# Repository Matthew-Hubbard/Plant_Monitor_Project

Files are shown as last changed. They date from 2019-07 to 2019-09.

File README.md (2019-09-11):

<h1 align="center" font-weight="bold">Wireless Plant Monitoring</h1>

### About
**Goal:** To host a website that tracks plant data through wireless sensors.

I'm developing a system of Arduinos with sensors to monitor plants connected over RF to a master module. The master module has an ESP8266 WiFi chip that uploads data to a Django web server via HTTP POST request.

### [Click here to check out the website!](http://matthewhubbard.pythonanywhere.com "Plant Monitor Website")

Demo

<h2 align="center">System Diagram</h2>

<p align="center">
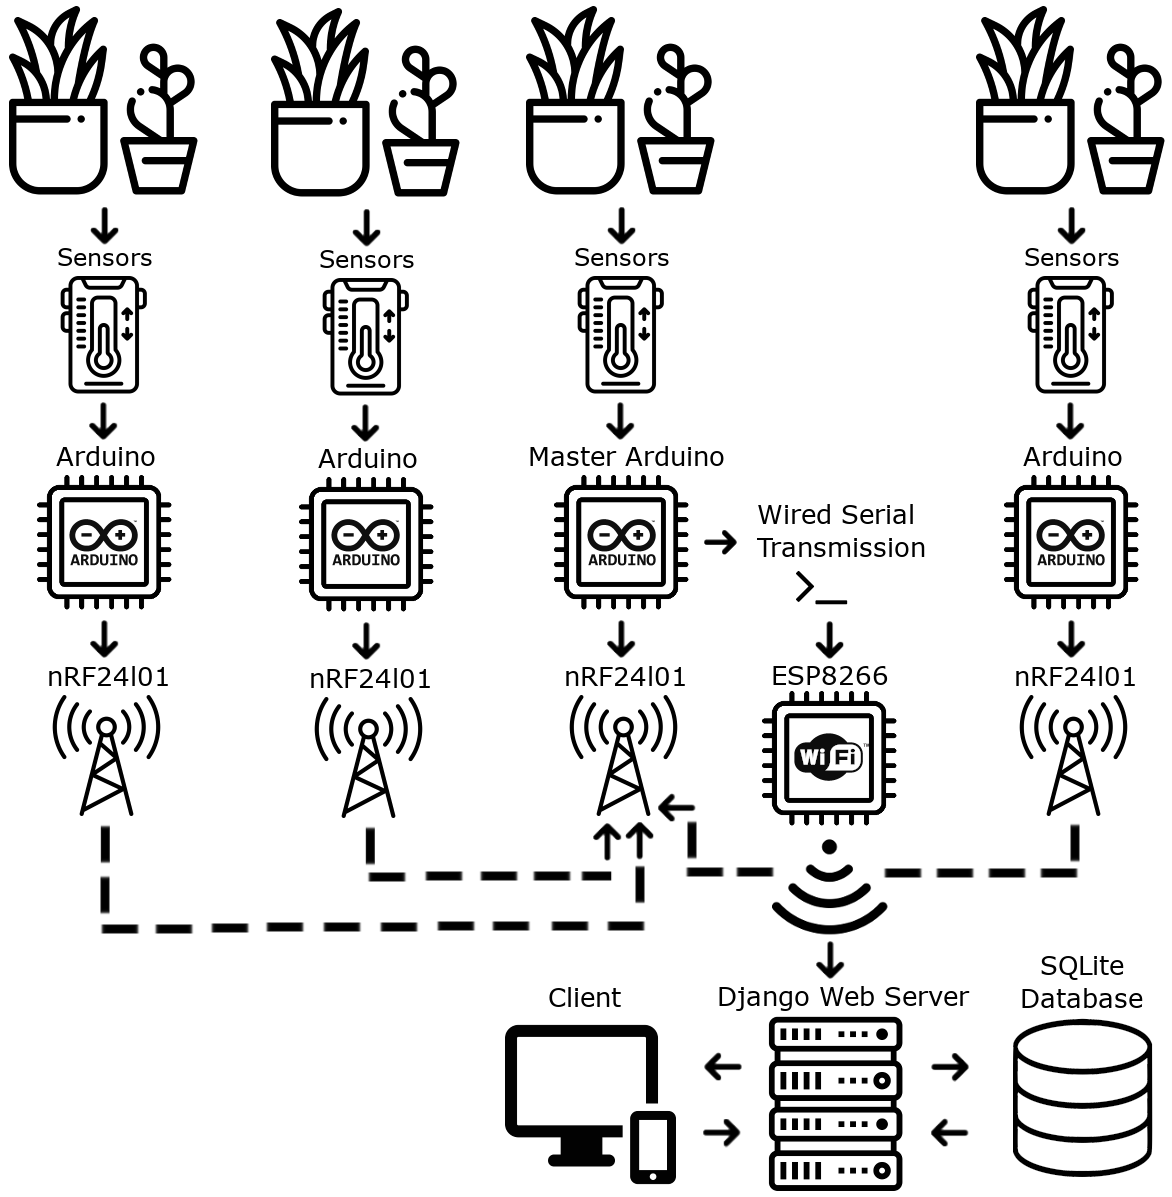
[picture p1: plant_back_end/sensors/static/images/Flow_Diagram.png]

</p>

<h2 align="center">Technology Stack</h2>
<hr>

<p align="center">

</p>

<p align="center">
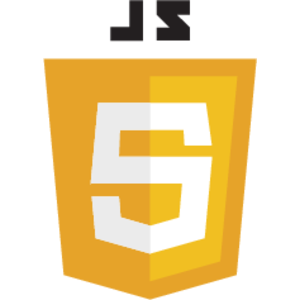
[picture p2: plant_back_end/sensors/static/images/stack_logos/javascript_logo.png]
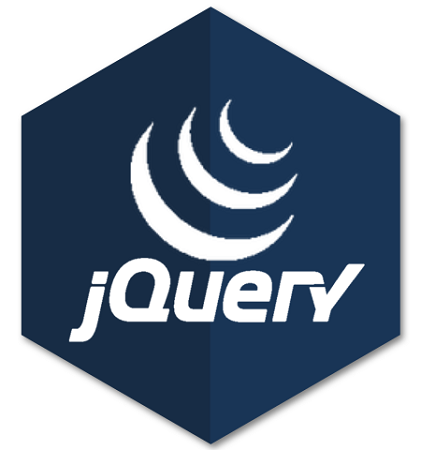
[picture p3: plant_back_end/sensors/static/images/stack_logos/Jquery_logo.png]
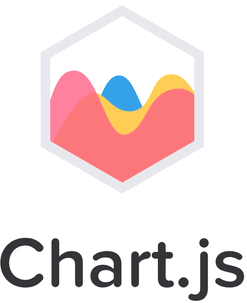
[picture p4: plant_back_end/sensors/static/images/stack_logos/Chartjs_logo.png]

</p>

<p align="center">
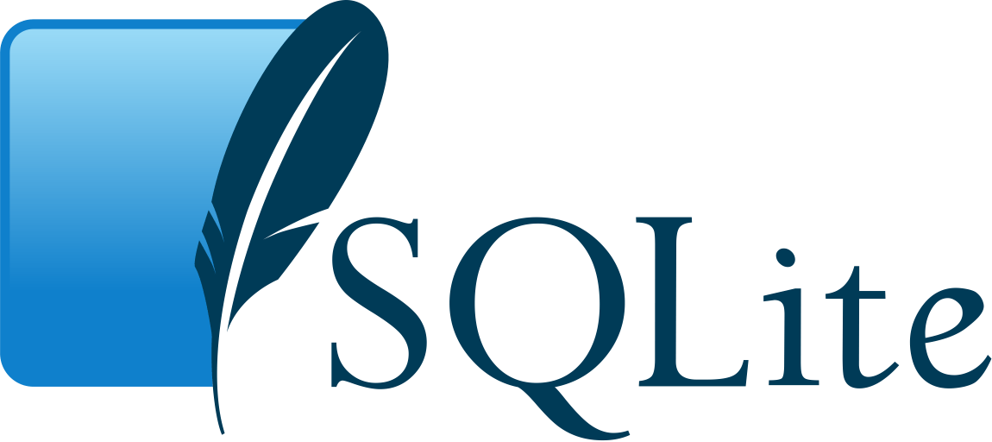
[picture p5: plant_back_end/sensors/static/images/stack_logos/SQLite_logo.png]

</p>

### Master Sensor With Wifi
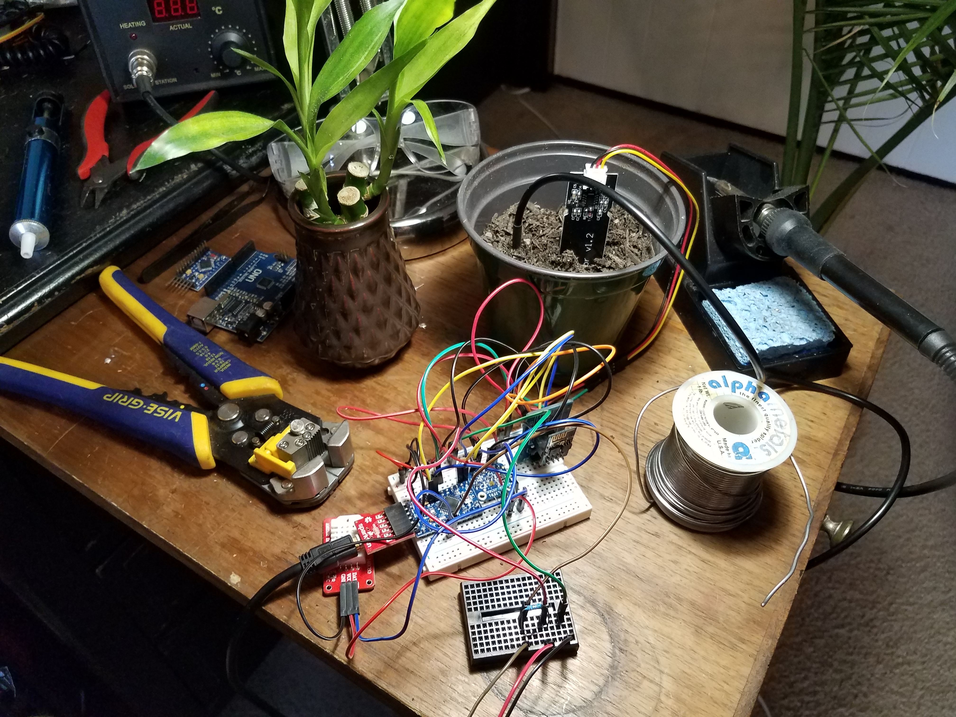
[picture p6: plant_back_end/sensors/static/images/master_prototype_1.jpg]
Master Sensor With Wifi


#### Data Collected From each Wireless Sensor Module
- Air Temperature
- Soil Temperature
- Sunlight Luminosity (Lux)
- Humidity
- Soil Moisture

## Wiring Diagrams
### Sensor Module
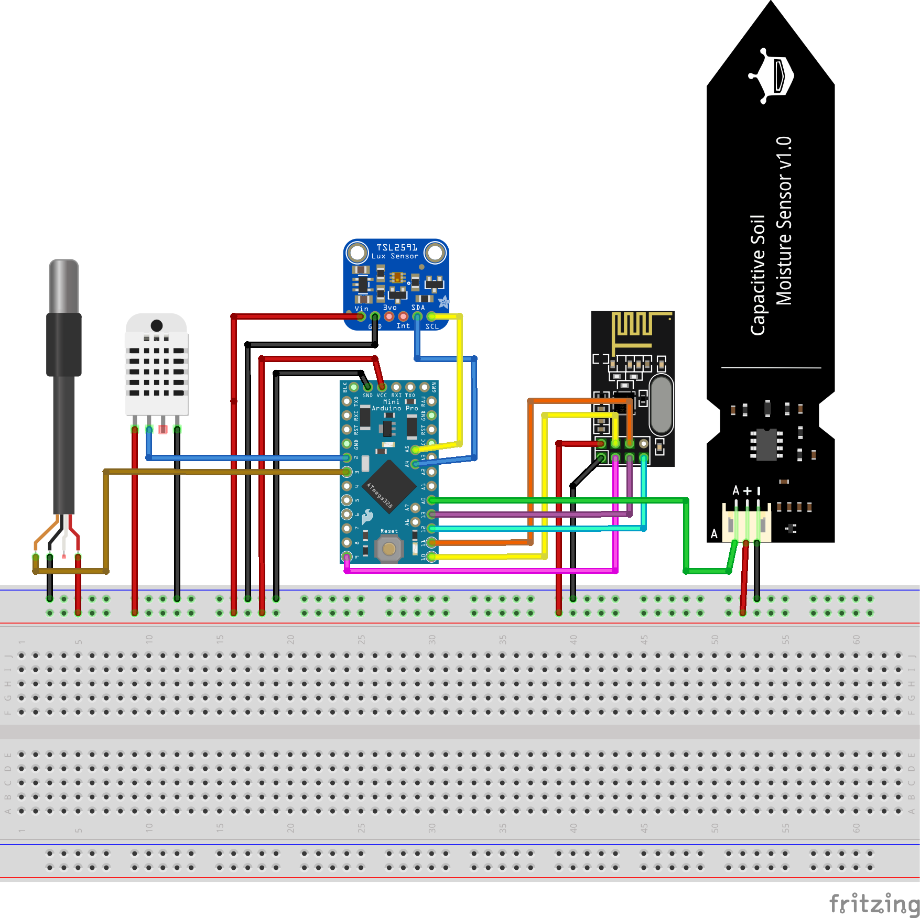
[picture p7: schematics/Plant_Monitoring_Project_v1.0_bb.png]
Fritzing Breadboard Wiring Diagram

<sup>\*Fritzing files available in the 'schematics' directory.</sup>
#### Components
- [Arduino Pro Mini 3.3v](https://www.sparkfun.com/products/11114)
- [nrf24l01+ RF Transceiver](https://www.sparkfun.com/datasheets/Components/SMD/nRF24L01Pluss_Preliminary_Product_Specification_v1_0.pdf) [(guide)](https://medium.com/@benjamindavidfraser/arduino-nrf24l01-communications-947e1acb33fb)
- [DHT22 Humidity and Temperature Sensor](https://www.adafruit.com/product/385)
- [Capacitive Soil Moisture Sensor v1.2](https://www.dfrobot.com/product-1385.html)
- [TSL2591 Lux Sensor](https://learn.adafruit.com/adafruit-tsl2591)
- [DS18B20 Waterproof Temperature Sensor (Cable)](https://www.adafruit.com/product/381)

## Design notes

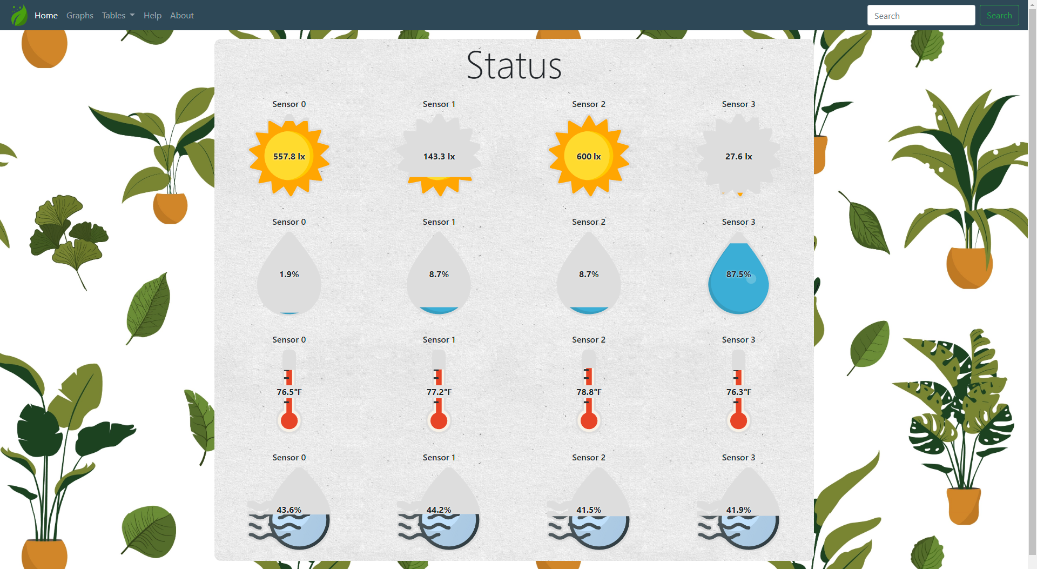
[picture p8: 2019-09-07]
Pictures/Homepage.PNG

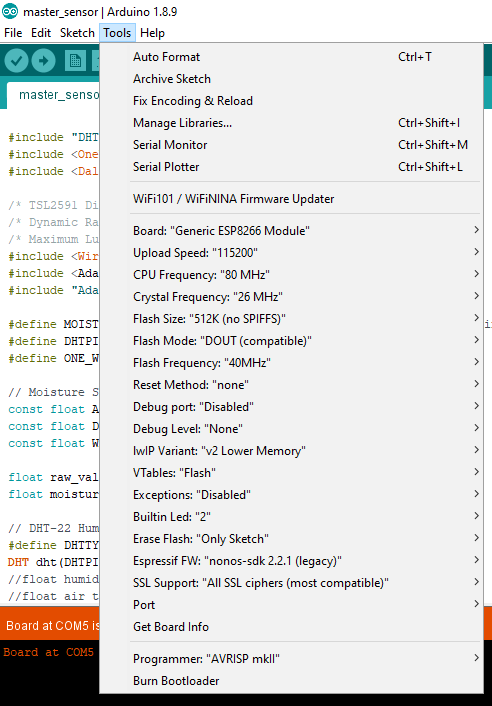
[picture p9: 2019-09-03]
Pictures/ESP8266_Arduino_IDE_Settings.png

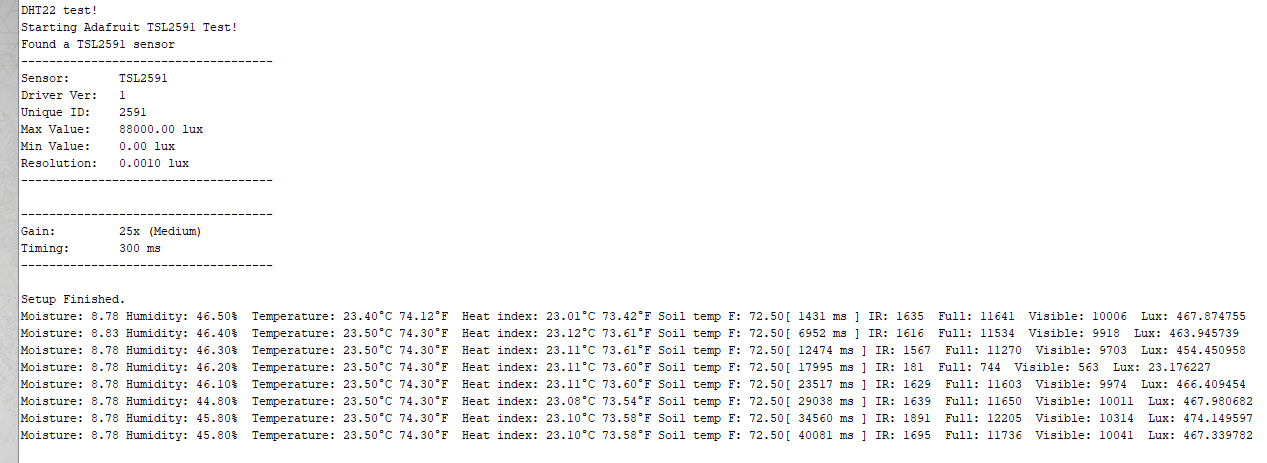
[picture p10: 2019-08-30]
Pictures/First_reading.PNG

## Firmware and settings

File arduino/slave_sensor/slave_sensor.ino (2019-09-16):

#include "DHT.h" // DHT library
#include <OneWire.h> // Used for soil temp probe
#include <DallasTemperature.h> // Used for soil temp probe
#include <Wire.h> // TSL2591 light sensor
#include <Adafruit_Sensor.h> // TSL2591 light sensor
#include "Adafruit_TSL2591.h" // TSL2591  light sensor (Dynamic Range: 600M:1, Max Lux: 88k)
#include <RF24Network.h> // nrf2401+
#include <RF24.h> // nrf2401+
#include <SPI.h> // nrf2401+

// Pins
#define MOISTURE_PIN 0 // Moisture sensor data connected to analog pin 0
#define DHTPIN 2
#define SOIL_TEMP_PIN 3 // Soil temp data pin

// Uno
// #define MOISTURE_PIN 0 // Moisture sensor data connected to analog pin 0
// #define DHTPIN A0
// #define SOIL_TEMP_PIN A1 // Soil temp data pin


// nrf2401+
// Hardware configuration: Set up nRF24L01 radio on SPI bus plus pins 7 & 8
uint8_t sensor_id = 1;
RF24 radio(7, 8);
RF24Network network(radio);
const uint16_t master_node = 00;
const uint16_t this_node = 01;
struct packet
{
  uint8_t sensor_id;
  uint8_t packet_number;
  char data[30];
};
String payload1 = "";
String payload2 = "";

float moisture_raw = 0.0;

// DHT-22 Humidity/Air Temp Vars
#define DHTTYPE 22 
DHT dht(DHTPIN, DHTTYPE);
struct dht_data_struct
{
  float humidity = 0.0;
  float air_temp_c = 0.0;
  float air_temp_f = 0.0;
  float heat_index_c = 0.0;
  float heat_index_f = 0.0;
};
dht_data_struct dht_data; // holds all of dht22 data

struct light_sensor
{
  uint32_t lum = 0;
  uint16_t ir = 0;
  uint16_t full = 0;
  uint16_t visible = 0;
  float lux = 0;
};
light_sensor light_data; // holds all of the TSL2591 light sensor data

const int SERIAL_DELAY = 250;
const int SERIAL_ITTER = 100;
String msg = "";

OneWire oneWire(SOIL_TEMP_PIN);
DallasTemperature sensors(&oneWire);
float Celcius=0;
float temp_soil=0;

Adafruit_TSL2591 tsl = Adafruit_TSL2591(2591); // pass in a number for the sensor identifier (for your use later)


// Functions
float get_moisture();
void get_dht(dht_data_struct & dht_in);
void configureSensor(void); // tsl2591 lux
void displaySensorDetails(void); //lux 
void advancedRead(light_sensor & light_data); //lux
void print_packet(packet & my_packet);

//////////////////////////////////////////////////////////////

void setup() {
  // Start serial for debugging
  Serial.begin(9600);
  // while(!Serial); //wait until serial is setup

  Serial.begin(9600);
  SPI.begin();
  radio.begin();
  network.begin(90, this_node);
  Serial.println("[Arduino] : nrf2401+ setup complete.");

  //DHT22
  Serial.println(F("[Arduino] : DHT22 test!"));
  dht.begin();

  //Soil temp
  sensors.begin();

  Serial.println(F("[Arduino] : Starting Adafruit TSL2591 Test!"));
  
  if (tsl.begin()) 
    Serial.println(F("[Arduino] : Found a TSL2591 sensor"));
  else 
  {
    Serial.println(F("[Arduino] : No sensor found ... check your wiring?"));
    while (1);
  }
    
  /* Display some basic information on this sensor */
  displaySensorDetails();
  
  /* Configure the sensor */
  configureSensor();

  delay(10000);
}

void loop() {
  network.update();

  packet request_packet;
  strcpy(request_packet.data, "");

#ifdef DEBUG_RF
  Serial.println("[Arduino] : Waiting for request from master");
#endif
  while (network.available())
  {
    RF24NetworkHeader header_in;
    network.read(header_in, &request_packet, 32);

    radio.flush_rx(); // Maybe remove??????

    String payload(request_packet.data);
    Serial.print("[Master] : ");
    print_packet(request_packet);
  }

  delay(100);

  network.update();
  if (strcmp(request_packet.data, "request") == 0)
  {
#ifdef DEBUG_RF
    Serial.println("[Arduino] : Got data request from master.");
#endif
    //if we've been requested to give data...

    packet data_out;
    data_out.sensor_id = sensor_id;

    RF24NetworkHeader header_out(master_node); // (Adress where the data is sent)

    if (request_packet.packet_number == 1)
    {
      //gather data
      gather_data(payload1, payload2);

      data_out.packet_number = 1;
      payload1.toCharArray(data_out.data, 30);

      Serial.print("[Arduino] : Sending ");
      print_packet(data_out);

      /* bool ok = */ network.write(header_out, &data_out, 32); // Sending the data to master_node
    }
    else if (request_packet.packet_number == 2 /* && payload2 != "" */)
    {
      data_out.packet_number = 2;
      payload2.toCharArray(data_out.data, 30);

      Serial.print("[Arduino] : Sending ");
      print_packet(data_out);

      /* bool ok = */ network.write(header_out, &data_out, 32); // Sending the data to master_node
    }
  }

/*
  if(request_packet.packet_number == 2)
  {
    Serial.print("[Arduino] : Sleeping");
    for(int i = 0; i < 10; ++i)
    {
      Serial.print(".");
      delay(100);
    }
    Serial.println();
  }
*/

}

/////////////////////-FUNCTIONS-///////////////////////////

void print_packet(packet &my_packet)
{
  Serial.print(my_packet.sensor_id);
  Serial.print(", ");
  Serial.print(my_packet.packet_number);
  Serial.print(", ");
  Serial.println(my_packet.data);
}

void gather_data(String & payload1, String & payload2)
{
  Serial.print("[Arduino] : Sensor ID: "); Serial.print(sensor_id); Serial.print(" ");
  moisture_raw = get_moisture();
  Serial.print("Moisture: ");
  Serial.print(moisture_raw);

  get_dht(dht_data);
  Serial.print(F(" Humidity: "));
  Serial.print(dht_data.humidity);
  Serial.print(F("%  Temperature: "));
  Serial.print(dht_data.air_temp_c);
  Serial.print(F("°C "));
  Serial.print(dht_data.air_temp_f);
  Serial.print(F("°F  Heat index: "));
  Serial.print(dht_data.heat_index_c);
  Serial.print(F("°C "));
  Serial.print(dht_data.heat_index_f);
  Serial.print(F("°F"));

  //Soil temp probe ***CHANGE TO USE STRUCT AND CALL FUNC****
  sensors.requestTemperatures();
  Celcius=sensors.getTempCByIndex(0);
  temp_soil=sensors.toFahrenheit(Celcius);
  //Serial.print(Celcius);
  Serial.print(" Soil temp F: ");
  Serial.print(temp_soil);  

  advancedRead(light_data);

  Serial.print(F(" IR: ")); Serial.print(light_data.ir);  Serial.print(F("  "));
  Serial.print(F("Full: ")); Serial.print(light_data.full); Serial.print(F("  "));
  Serial.print(F("Visible: ")); Serial.print(light_data.visible); Serial.print(F("  "));
  Serial.print(F("Lux: ")); Serial.println(light_data.lux, 6);

  //Send to master sensor
  payload1 = String(sensor_id) + String(';') + \
  String(temp_soil) + String(';') + \
  String(dht_data.air_temp_f) + String(';') + \
  String(dht_data.humidity) + String(';') + \
  String(moisture_raw) + String(';');

  payload2 = String(dht_data.heat_index_f) + String(';') + \
  String(light_data.lux) + String(';') + \
  String(light_data.visible) + String(';') + \
  String(light_data.ir) + String(';') + \
  String(light_data.full) + String(';');
}

float get_moisture()
{
  moisture_raw = analogRead(MOISTURE_PIN); //connect sensor to Analog 0
  //return ((DRY_SOIL - moisture_raw)/(DRY_SOIL - WATERED)) * 10.0;
  return moisture_raw;
}

void get_dht(dht_data_struct & dht_in)
{
  // Reading temperature or humidity takes about 250 milliseconds!
  // Sensor readings may also be up to 2 seconds 'old' (its a very slow sensor)
  dht_in.humidity = dht.readHumidity();
  // Read temperature as Celsius (the default)
  dht_in.air_temp_c = dht.readTemperature();
  // Read temperature as Fahrenheit (isFahrenheit = true)
  dht_in.air_temp_f = dht.readTemperature(true);

  // Check if any reads failed and exit early (to try again).
  if (isnan(dht_in.humidity) || isnan(dht_in.air_temp_c) || isnan(dht_in.air_temp_f)) {
    Serial.println(F("Failed to read from DHT sensor!"));
    return;
  }

  // Compute heat index in Fahrenheit (the default)
  dht_in.heat_index_f = dht.computeHeatIndex(dht_in.air_temp_f, dht_data.humidity);
  // Compute heat index in Celsius (isFahreheit = false)
  dht_in.heat_index_c = dht.computeHeatIndex(dht_in.air_temp_c, dht_data.humidity, false);
  return;
}

void configureSensor(void)
{
  // You can change the gain on the fly, to adapt to brighter/dimmer light situations
  //tsl.setGain(TSL2591_GAIN_LOW);    // 1x gain (bright light)
  tsl.setGain(TSL2591_GAIN_MED);      // 25x gain
  //tsl.setGain(TSL2591_GAIN_HIGH);   // 428x gain
  
  // Changing the integration time gives you a longer time over which to sense light
  // longer timelines are slower, but are good in very low light situtations!
  //tsl.setTiming(TSL2591_INTEGRATIONTIME_100MS);  // shortest integration time (bright light)
  // tsl.setTiming(TSL2591_INTEGRATIONTIME_200MS);
  tsl.setTiming(TSL2591_INTEGRATIONTIME_300MS);
  // tsl.setTiming(TSL2591_INTEGRATIONTIME_400MS);
  // tsl.setTiming(TSL2591_INTEGRATIONTIME_500MS);
  // tsl.setTiming(TSL2591_INTEGRATIONTIME_600MS);  // longest integration time (dim light)

  /* Display the gain and integration time for reference sake */  
  Serial.println(F("------------------------------------"));
  Serial.print  (F("Gain:         "));
  tsl2591Gain_t gain = tsl.getGain();
  switch(gain)
  {
    case TSL2591_GAIN_LOW:
      Serial.println(F("1x (Low)"));
      break;
    case TSL2591_GAIN_MED:
      Serial.println(F("25x (Medium)"));
      break;
    case TSL2591_GAIN_HIGH:
      Serial.println(F("428x (High)"));
      break;
    case TSL2591_GAIN_MAX:
      Serial.println(F("9876x (Max)"));
      break;
  }
  Serial.print  (F("Timing:       "));
  Serial.print((tsl.getTiming() + 1) * 100, DEC); 
  Serial.println(F(" ms"));
  Serial.println(F("------------------------------------"));
  Serial.println(F(""));
}

void displaySensorDetails(void)
{
  sensor_t sensor;
  tsl.getSensor(&sensor);
  Serial.println(F("------------------------------------"));
  Serial.print  (F("Sensor:       ")); Serial.println(sensor.name);
  Serial.print  (F("Driver Ver:   ")); Serial.println(sensor.version);
  Serial.print  (F("Unique ID:    ")); Serial.println(sensor.sensor_id);
  Serial.print  (F("Max Value:    ")); Serial.print(sensor.max_value); Serial.println(F(" lux"));
  Serial.print  (F("Min Value:    ")); Serial.print(sensor.min_value); Serial.println(F(" lux"));
  Serial.print  (F("Resolution:   ")); Serial.print(sensor.resolution, 4); Serial.println(F(" lux"));  
  Serial.println(F("------------------------------------"));
  Serial.println(F(""));
  delay(500);
}

void advancedRead(light_sensor & light_data)
{
  light_data.lum = tsl.getFullLuminosity();
  light_data.ir = light_data.lum >> 16;
  light_data.full = light_data.lum & 0xFFFF;
  light_data.visible = light_data.full - light_data.ir;
  light_data.lux = tsl.calculateLux(light_data.full, light_data.ir);
}

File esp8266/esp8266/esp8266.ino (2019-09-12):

#include <Arduino.h>
#include <ESP8266WiFi.h>
#include <WiFiClient.h>
#include <ESP8266HTTPClient.h>

#ifndef STASSID
//#define STASSID "Samsung Galaxy S7 8574"
//#define STAPSK  "auhq4212"
//#define IP "192.168.43.225"

#define STASSID "CenturyLink0853"
#define STAPSK  "htizeeynhc9wm7"
#define IP "192.168.0.72"
#endif

const char* ssid = STASSID;
const char* password = STAPSK;

int recieve_data(String & data);
int send_data(const String & data);
const int SERIAL_DELAY = 500;
const int SERIAL_ITTER = 500;
const char delimiter = ';';

String get_payload();
String get_data(const String & sensor_data, int & pos, const int & len);

void setup() {
  Serial.begin(9600);
  WiFi.mode(WIFI_STA);
  WiFi.begin(ssid, password);

  // Wait for connection
  while (WiFi.status() != WL_CONNECTED) {
    delay(500);
  }
}

void loop() {
  // wait for WiFi connection

  WiFiClient client;
  HTTPClient http;

  if(http.begin(client, "http://" + String(IP) + ":8000/sensors/send_data/"))
  {
    http.addHeader("Content-Type", "multipart/form-data; boundary=boundary");

    //String payload = "--boundary\r\nContent-Disposition: form-data; name=\"sensor_id\"\r\n\r\n7\r\n--boundary\r\nContent-Disposition: form-data; name=\"temp_soil\"\r\n\r\n11.11\r\n--boundary\r\nContent-Disposition: form-data; name=\"temp_room\"\r\n\r\n22.22\r\n--boundary\r\nContent-Disposition: form-data; name=\"humidity\"\r\n\r\n33.33\r\n--boundary\r\nContent-Disposition: form-data; name=\"heat_index\"\r\n\r\n44.44\r\n--boundary\r\nContent-Disposition: form-data; name=\"moisture\"\r\n\r\n55.55\r\n--boundary\r\nContent-Disposition: form-data; name=\"lux\"\r\n\r\n66.66\r\n--boundary\r\nContent-Disposition: form-data; name=\"visible\"\r\n\r\n777\r\n--boundary\r\nContent-Disposition: form-data; name=\"ir\"\r\n\r\n888\r\n--boundary\r\nContent-Disposition: form-data; name=\"full\"\r\n\r\n999\r\n--boundary--"; // Get formatted HTTP POST request from arduino via serial String payload = get_payload();
    String payload = get_payload();

    // Send post request with payload (upload sensor data to Django web server)
    int httpCode = http.POST(payload);
  }

  delay(100);
}

String get_payload()
{
  String sensor_data = "";
  int pos = 0;
  int len = 0;
  String data = "";
  String payload = "";

  recieve_data(sensor_data);
  // sensor_data = "9;71.15;73.76;59.50;73.63;621.00;243.84;5615;1419;7034;";
  len = sensor_data.length();

  // Extract data from sensor_data and format HTTP POST form request
  payload = "--boundary\r\nContent-Disposition: form-data; name=\"sensor_id\"\r\n\r\n";
  data = get_data(sensor_data, pos, len);
  payload += data;

  payload += "\r\n--boundary\r\nContent-Disposition: form-data; name=\"temp_soil\"\r\n\r\n";
  data = get_data(sensor_data, pos, len);
  payload += data;

  payload += "\r\n--boundary\r\nContent-Disposition: form-data; name=\"temp_room\"\r\n\r\n";
  data = get_data(sensor_data, pos, len);
  payload += data;
  
  payload += "\r\n--boundary\r\nContent-Disposition: form-data; name=\"humidity\"\r\n\r\n";
  data = get_data(sensor_data, pos, len);
  payload += data;

  payload += "\r\n--boundary\r\nContent-Disposition: form-data; name=\"heat_index\"\r\n\r\n";
  data = get_data(sensor_data, pos, len);
  payload += data;

  payload += "\r\n--boundary\r\nContent-Disposition: form-data; name=\"moisture\"\r\n\r\n";
  data = get_data(sensor_data, pos, len);
  payload += data;

  payload += "\r\n--boundary\r\nContent-Disposition: form-data; name=\"lux\"\r\n\r\n";
  data = get_data(sensor_data, pos, len);
  payload += data;

  payload += "\r\n--boundary\r\nContent-Disposition: form-data; name=\"visible\"\r\n\r\n";
  data = get_data(sensor_data, pos, len);
  payload += data;

  payload += "\r\n--boundary\r\nContent-Disposition: form-data; name=\"ir\"\r\n\r\n";
  data = get_data(sensor_data, pos, len);
  payload += data;

  payload += "\r\n--boundary\r\nContent-Disposition: form-data; name=\"full\"\r\n\r\n";
  data = get_data(sensor_data, pos, len);
  payload += data;

  payload += "\r\n--boundary--";
  return payload;
}

String get_data(const String & sensor_data, int & pos, const int & len)
{
  String data = "";

  if(pos >= len)
  {
    // out of bounds!
    data = "-";
    return data;
  }

  while(pos < len && sensor_data[pos] != delimiter) 
  {
    data += sensor_data[pos];
    ++pos;
  }
  ++pos;
  return data;
}

int recieve_data(String & data)
{
  data = "";
  int i = 0;

  // Wait for Serial read buffer to be empty...
  while(!Serial.available() && i < SERIAL_ITTER) {++i;} 

  if(i == SERIAL_ITTER - 1 )
  {
    // Serial not available to read! (read buffer not empty!)");
    recieve_data(data);
    return -1;
  }

  //get data from Arduino Sensor
  i = 0;
  while (Serial.available() && i < SERIAL_ITTER)
  {
    data = Serial.readString();
    ++i;
  }

  if(i >= SERIAL_ITTER - 1)
  {
    //[ERROR] : Couldn't recieve data
    recieve_data(data);
    return -2;
  }

  // Send data back to Arduino Sensor to confirm transmition
  int num_bytes = Serial.availableForWrite(); // check if we have anything still in write buffer
  if(num_bytes > 0)
  {
    // [ERROR] : bytes already in write buffer...
    Serial.flush();
  }
  
  // Sending data over serial to arduino sensor
  delay(SERIAL_DELAY);
  if(data != "")
    Serial.write(data.c_str());
  else
    recieve_data(data);
    
  return 0;
}

/*
// If I need to send data to Arduino in the future...

int send_data(const String & data)
{
  String recieved = ""; // message back from serial
  int i = 0;
  int num_bytes = Serial.availableForWrite(); // check if we have anything still in write buffer
  if(num_bytes > 0)
  {
    Serial.flush();
  }
  
  // Sending data over serial
  Serial.write(data.c_str());

  delay(SERIAL_DELAY);

  // Now wait for confirmation from ESP. ESP Should send data back to confirm.

  while(!Serial.available() && i < SERIAL_ITTER) {++i;} // Wait for Serial read buffer to be empty...

  if(i == SERIAL_ITTER - 1 )
  {
    //Serial.print("[ESP] [ERROR] : Serial not available to read! (read buffer not empty!)");
    return -1;
  }

  i = 0;
  while(recieved != data && i < SERIAL_ITTER)
  {
    //while (Serial.available())
    {
      recieved = Serial.readString();
    }
    ++i;
  }
  if(i >= SERIAL_ITTER - 1)
  {
    return -2;
  }
  else
  {
    Serial.flush();
    return 0;
  }
}
*/

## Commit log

2019-07-05 Started over with a new django app. Made a Sensor_data model to store sensor data to. Added one dummy data from python manage.py shell.
2019-07-05 Created a basic Sensor_data model in sensors app. Setup admin account with the model and super user admin (password in keepass). Don't have API implemented yet.
2019-07-05 merged branch into master. Current state is Sensor_data model created. Admin is setup. No API functionality.
2019-07-11 Successfully added form data to Sensor_data model via POST request using postman. Created forms.py to create a form from Sensor_data model. Then in views.py I look for a POST request coming from /sen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
2019-07-13 added esp8266 code to send a http POST request. Right now just sending test data with a raw json payload in the body. Server doesn't actually do anything with the data but I can see the body was reci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
    [views.py]
2019-07-13 Had to rename folder to match ino file so arduino ide would let me edit it.
2019-07-22 Added fritzing breadboard diagram (png and fzz). Found fritzing models of components and uploaded for portability.
    [Plant_Monitoring_Project_v1.0.fzz]
2019-07-22 Added About section and wiring diagram image.
2019-08-30 Arduino code: Now reading all sensor data and outputting to serial out. Read dev logs 8-29-19 for details.
2019-09-01 Added more fields to model and updated form. Fields added: sensor_id, heat_index, visible, ir, full
2019-09-01 got a rough version working that responds with json from sensor. Has backslash in fields though and not using drf.
2019-09-01 Created an index.html template page for sensors app that displays all sensor data in a template. Created a static folder with my css file.
2019-09-03 Created some testing files to transmit data over serial to and from arduino and esp. Got it transmitting reliably using SoftwareSerial.h.
2019-09-03 Forgot to include serial test file for arduino.
2019-09-05 Can now upload sensor data from arduino to esp to django backend. Serial connection correctly transmitting data from arudino to esp.
    [esp8266.ino, master_sensor.ino]
2019-09-06 merged chart branch. Now webpage will display a graph of sensor 0 soil temperature.
2019-09-06 added lux graph. need to take another look at the graphs to make sure they are displaying the correct data and time.
    [views.py]
2019-09-06 Got multiple sensors displaying properly. Going to try to make a more general function to generate graphs to reduce code.
2019-09-07 Updated navbar. Got links working from homepage to graphs (Still need to fix active nav link). Put graph context into helper function. Fixed loading-bar plugin. About to implement custom loading bar 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
    [views.py]
2019-09-08 Added tooltip notifications that show up on hover. Will tell you to water you plant if the moisture sensor is low etc. Also added some prototype pictures for the readme and about section.
2019-09-08 Created alerts that pop up when a sensor has certain readings such as needing to be watered.
2019-09-09 Updated table tab. Fixed navbar active. Created about page and help page. Uploaded more images to static.
    [views.py]
2019-09-10 Uploaded logos for my tech stack for README. Gathered more sensor data.
2019-09-10 Created a flow diagram with Gimp and icons from flaticon. Shows high level picture of system.
2019-09-10 Updated flow diagram to specify Master arduino unit.
2019-09-11 Uploaded a webm demo of the current site. Testing to put in on the README. Might need to convert to .gif
2019-09-11 Cleaned up some of the arduino and esp code.
2019-09-15 Created a network protocol to transfer data from sensors to master sensor over rf. Testing files work in arduino/testing_files. Master sensor requests sensor id and packet_number and sensor responds 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
2019-09-15 Got RF transmission working with actual data from sensors!! There could still be improvements to the protocol but it is working consistently.Might have to discard sensors on master due to low memory.
2021-03-19 Bump djangorestframework from 3.9.2 to 3.11.2 in /plant_back_end
    Bumps [djangorestframework](https://github.com/encode/django-rest-framework) from 3.9.2 to 3.11.2.
    - [Release notes](https://github.com/encode/django-rest-framework/releases)
    - [Commits](https://github.com/encode/django-rest-framework/compare/3.9.2...3.11.2)
